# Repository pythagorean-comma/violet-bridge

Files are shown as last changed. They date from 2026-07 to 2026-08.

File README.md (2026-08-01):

# violet-bridge
CadQuery based python scripts to generate STEP and SVG renderings of components of a viola da gamba bridge.
The bridge saddles can be moved fore and aft to allow fine intonation adjustments
The saddles have recesses such that RMC pizz/arco pickups can be installed.

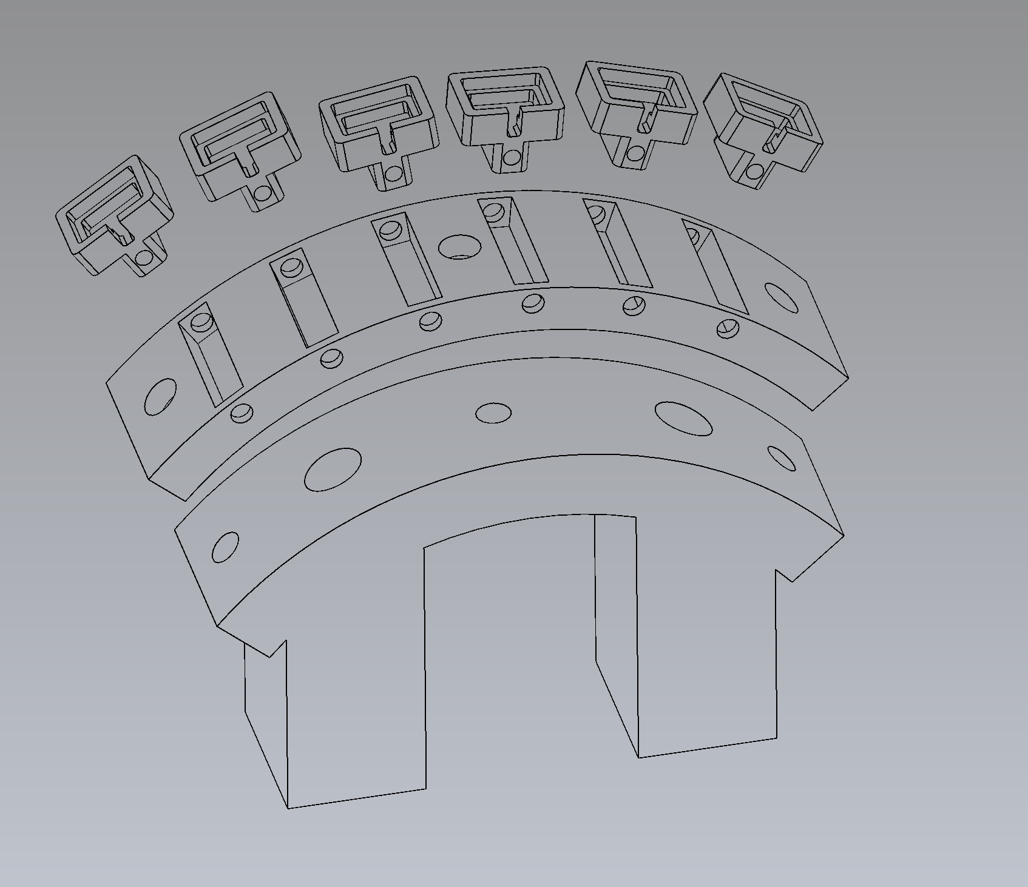
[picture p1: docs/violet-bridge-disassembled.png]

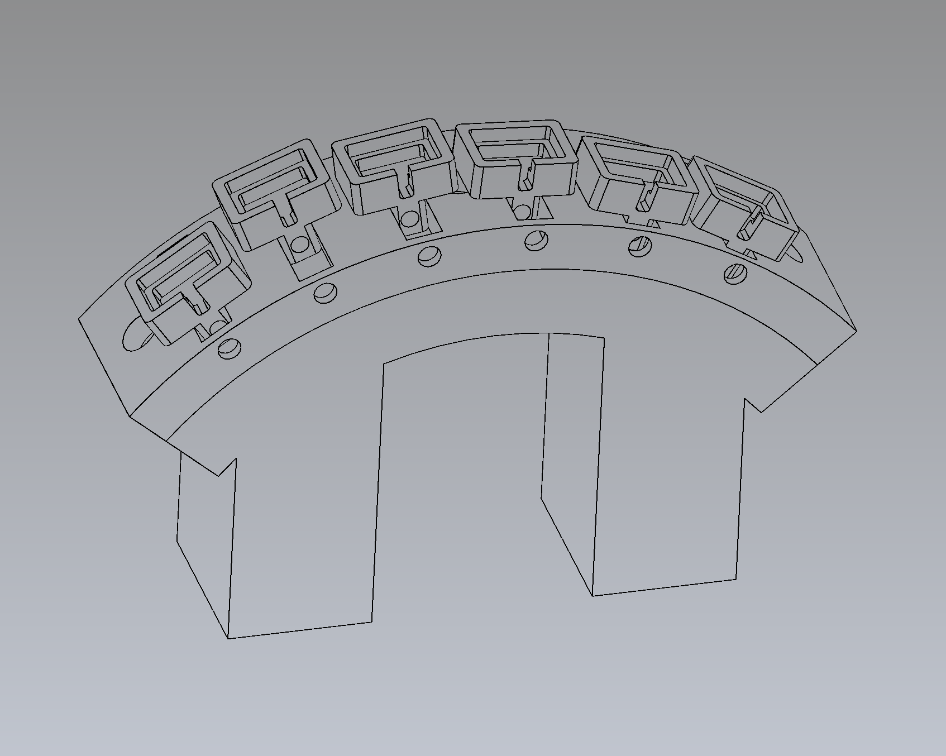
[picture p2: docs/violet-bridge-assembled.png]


## Requirements

`bridge.py`, `bridge_body.py`, `assembly.py`:

```bash
python3 -m venv .venv && .venv/bin/pip install -r requirements.txt
.venv/bin/python assembly.py
```

Python 3.10–3.12. Use `.venv/bin/python` rather than a bare `python`.

## Pickup electronics

The phase-switching preamp for the RMC pizz/arco pickups that sit in the
saddles has its own repository:
<https://github.com/pythagorean-comma/rmc-pizz-arco>. It was extracted from
this one on 2026-08-01 — it shares no dependencies with the bridge geometry
and needs KiCad rather than CadQuery.

The board's history up to that point is in this repository, at the
`electronics/` path. That includes the original 88 × 112 mm hand-buildable
version, which the new repository does not carry:

```bash
git checkout a670b3e -- electronics/
```

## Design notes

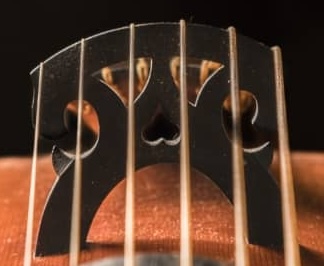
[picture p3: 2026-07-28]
docs/vdg-bridge.jpg

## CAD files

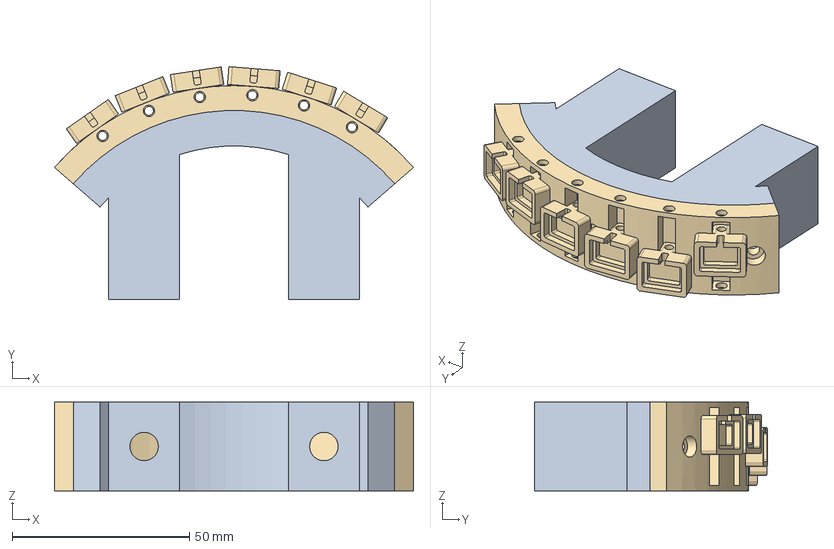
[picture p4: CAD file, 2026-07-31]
out/bridge_assembly.step
101.2 x 65.6 x 25.0 mm
bridge_body
crown
saddle_1
saddle_2
saddle_3
saddle_4
saddle_5
saddle_6

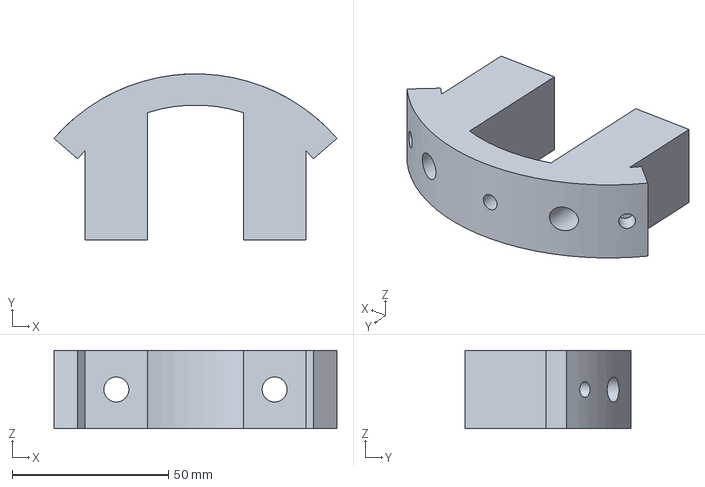
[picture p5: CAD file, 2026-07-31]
out/bridge_body.step
90.6 x 53.2 x 25.0 mm

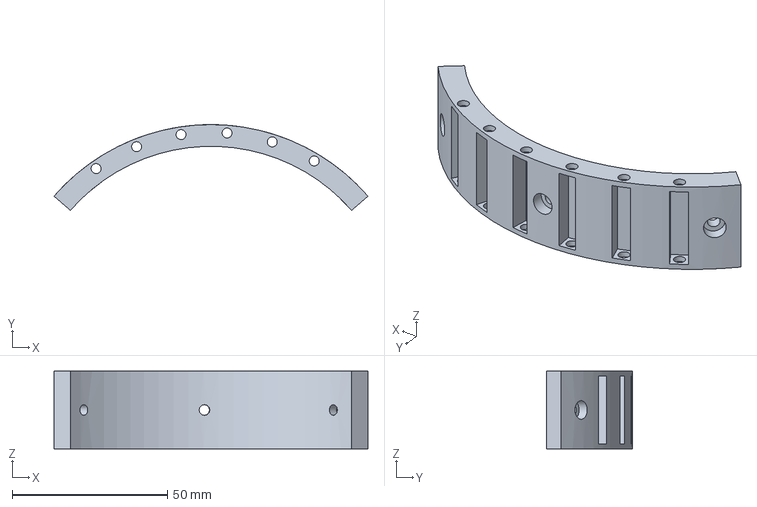
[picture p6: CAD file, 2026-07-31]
out/saddle_bridge.step
101.2 x 27.7 x 25.0 mm

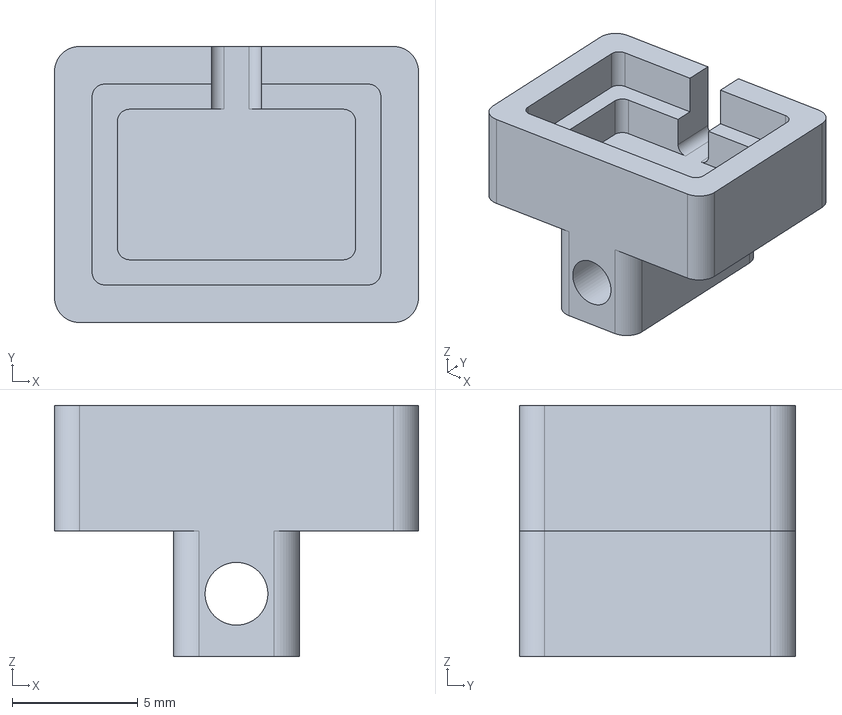
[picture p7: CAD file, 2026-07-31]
out/intonation-carriage.step
14.5 x 11.0 x 10.0 mm

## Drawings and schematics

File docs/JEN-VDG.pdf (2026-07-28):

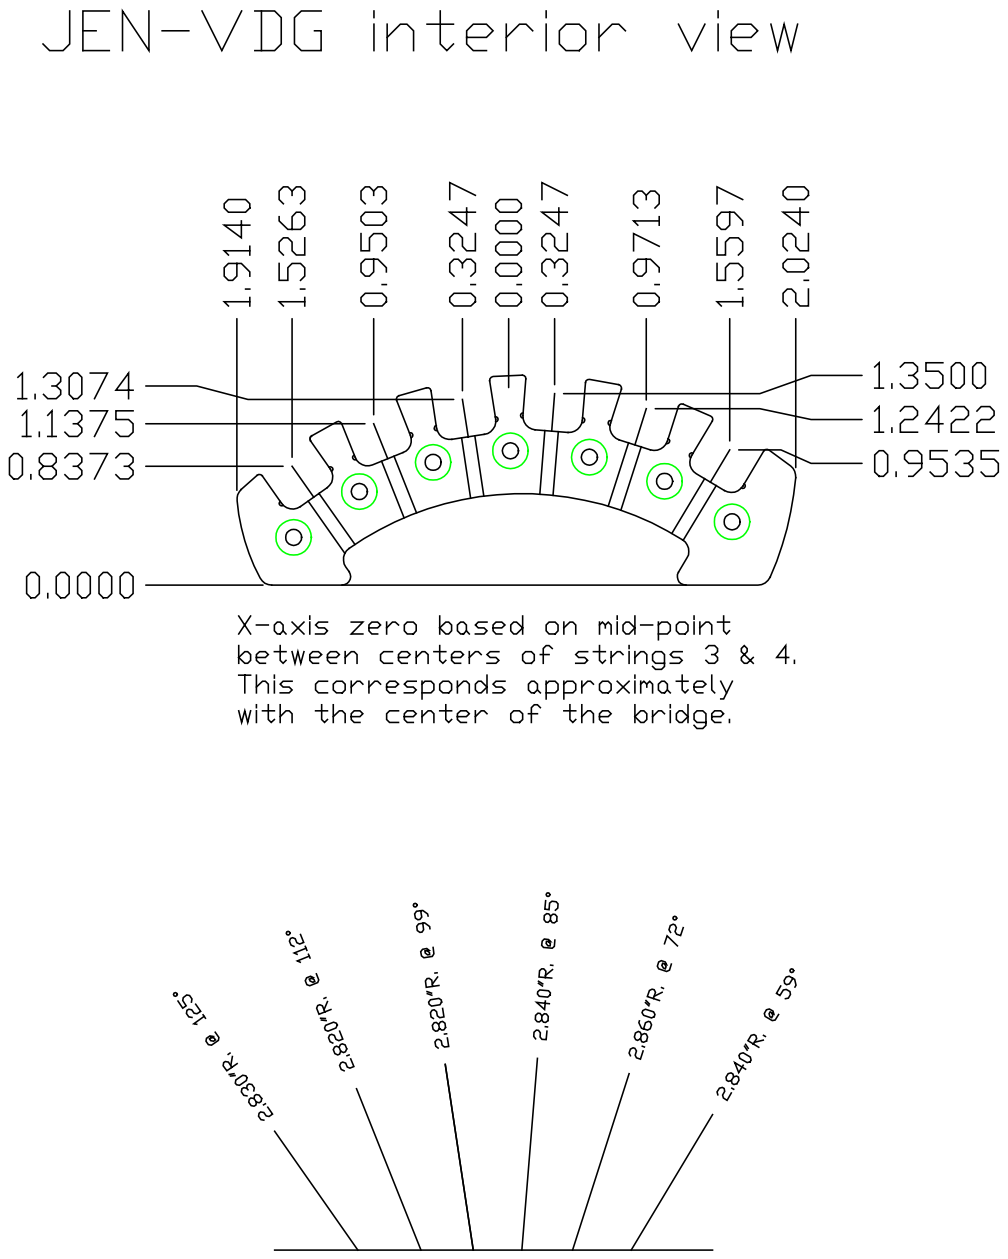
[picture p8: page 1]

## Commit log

2026-07-28 Initial commit of CadQuery script
    [bridge_blank.step]
2026-07-28 Simplified bridge design and made it compatible with abr-1 style saddles with intonation screws. Leaving original Jensen VDG design in case we need to verify radius, string separation, degrees betwee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
    [bridge_blank.step, saddle_bridge.step]
2026-07-28 The original RMC/Jensen design had the strings rotated 2 degrees from centre. This assymetry is useful in that in gives the desired string heights so this has been reinstated
    [saddle_bridge.step]
2026-07-28 Added jpg of a target design
    [saddle_bridge.step]
2026-07-29 This part will dock on to another piece. To facilitate this we have refactored common data points and defs into a common.py. Also added fixing holes to the existing piece such that m3 bolts can be fi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
    [saddle_bridge.step]
2026-07-29 The crown was originally 13.1mm thick radially. We have reduced this to 7mm such that there is now 44% less material.
    [saddle_bridge.step]
2026-07-29 Initial modelling of bridge body
    [bridge_body.step, saddle_bridge.step]
2026-07-29 Moved outer two fixing holes to the outside of outer two strings
    [bridge_body.step, saddle_bridge.step]
2026-07-29 Added legs
    [bridge_body.step]
2026-07-29 Moved legs in 5mm towards centre to accomodate later fitting of a yamahiko contrabass pickup
    [bridge_body.step]
2026-07-29 Added script which assembles both parts for visual verification
    [bridge_assembly.step, bridge_body.step, saddle_bridge.step]
2026-07-29 Initial commit of printed circuit board design for pizz-arco phase shifting
    [rmc-pizz-arco.kicad_pcb, rmc-pizz-arco.kicad_sch]
2026-07-29 Fixed errors and wrote up notes
    [rmc-pizz-arco-B_Courtyard.gbr, rmc-pizz-arco-B_Cu.gbl, rmc-pizz-arco-B_Fab.gbr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]
2026-07-30 Fixed errors and wrote up pcbway order
    [bridge_assembly.step, bridge_body.step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]
2026-07-30 Made the assets accessible as a KiCad project
    [rmc-pizz-arco-B_Cu.gbl, rmc-pizz-arco-B_Mask.gbs, rmc-pizz-arco-B_Silkscreen.gbo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]
2026-07-30 We believe this system can be safely run at 9v DC. We now check for KiCad installation and fail if not found. We updated docs on what happens if the power supply fails.
    [bridge_assembly.step, bridge_body.step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]
2026-07-30 Made it clear that we believe this system can run on 9v
    [rmc-pizz-arco-B_Cu.gbl, rmc-pizz-arco-B_Mask.gbs, rmc-pizz-arco-B_Silkscreen.gbo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]
2026-07-30 Added the current state of the design. Clarifications from RMC will fundamentally change things. Awaiting repsonse before proceeding
2026-07-31 Power is delivered to the pc board via a modified version of the poly-drive ii
2026-07-31 added intonation carriage to this project to keep all assets in one place
    [bridge_blank.step, intonation-carriage.step]
2026-07-31 Updated assembly to include the intonation saddles
    [bridge_assembly.step, bridge_body.step, saddle_bridge.step]
2026-08-01 First pass at reworking board now we know that power will be provided by a modified poly-drive ii via pins 7 and 8
    [rmc-pizz-arco.kicad_pcb, rmc-pizz-arco.kicad_sch]
2026-08-01 DRC is down to 139 from 252 at the start of this session
    [rmc-pizz-arco.kicad_pcb]
2026-08-01 Route the board to DRC-clean: 139 violations to zero
    The routing is now entirely in gen_pcb.py; no autorouter is involved and
    none is needed. 139 -> 34 -> 21 -> 18 -> 1 -> 0, with 0 unconnected items.
    The full build passes: 53 nets and 233 pin connections matched against
    design.py, 80 footprints linked, ERC clean, and the fab package writes.
    Board measures 78.8 x 81.3 mm = 6406 mm2, against 88 x 112 = 9856 on main.
    What the six-at-a-time faults turned out to be, since they are what the
    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
    [rmc-pizz-arco-bom.csv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]
2026-08-01 Stage 5: bring the four documents up to the built board
    STATE.md, NOTES.md, ENCLOSURE.md and fab/ORDER.md all described a board that
    no longer exists. Each now describes the one that does.
    STATE.md was still saying the headroom question was open and no rework had
    started; both were false. It now opens with the built state and carries RMC's
    round-four answer with its date, the reasoning, and — the part that was
    missing — what would falsify it and what the fix would be if it were. The
    ~60 x 70 projection is replaced by the measured 78.8 x 81.3, along with an
    account of why the projection missed by 34%: counting parts rather than
    counting lanes, which is the same error as the two before it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
    [rmc-pizz-arco-B_Cu.gbl, rmc-pizz-arco-B_Mask.gbs, rmc-pizz-arco-B_Silkscreen.gbo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]
2026-08-01 Make the silkscreen legible
    Not a DRC error, and worse for it: the reference designators are what an
    assembler and a reviewer both work from, and half of them were unreadable.
    Three faults, all visible only in a render:
    - Adjacent blocks' sub-row designators landed on top of each other. KiCad
    puts a reference above its part, which for an odd channel points straight
    at the previous block's sub-row 2.8mm away. Sub-row designators now go
    towards their own row instead, mirrored by the channel's sign like
    everything else in a block.
    - Both bottom legends ran off both edges of the board, which a fab silently
    clips -- taking the polarity warning with it, the one piece of silkscreen
    th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
    [rmc-pizz-arco-B_Cu.gbl, rmc-pizz-arco-B_Mask.gbs, rmc-pizz-arco-B_Silkscreen.gbo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]
2026-08-01 Delete fab/board-top.svg -- a render of a board that no longer exists
    It was a top-layer render of the original 88 x 112 mm board (the SVG header
    still said 87.9856 x 111.9886 mm), two revisions behind the 78.8 x 81.3 mm
    board now in fab/. Committed by hand in a14ced1 and never touched since.
    It went stale because it was the one file in fab/ that build.sh did not
    produce, so no build could ever refresh it -- sitting among twelve current
    outputs, where it invited being taken for one of them. That is the whole
    argument for removing it rather than regenerating it: fab/ is trustworthy
    exactly to the extent that everything in it is generated.
    Nothing referenced it. RMC-QUESTIONS.md mentions bui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
2026-08-01 Make free_offset() measure pad edges, not pad centres
    Carried over from a parallel read-only session that spotted it while working
    the same routing problem. It is the one observation from that design still
    worth acting on -- the rest was overtaken by the route that shipped.
    The test compared pad CENTRES against a single 0.55mm scalar. It could not
    tell a 1206's 1.12 x 1.75mm pad from a 2.54mm header's 1.70mm square one, and
    a via needs 0.5mm of room from a pad's EDGE (0.3 radius + 0.2 clearance), so
    clearing a header pad needs 1.35mm between centres. The test asked for 0.55.
    It also counted same-net pads, which need no clearance at all.
    Demonstrated on real geometry: J1.1 and J1.2 are 2.54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
2026-08-01 Move the pickup electronics out to its own repository
    The board is finished and has nothing in common with the bridge geometry it
    was sitting beside: it needs KiCad, not CadQuery, and shares no dependency
    with anything else here. It now lives at
    https://github.com/pythagorean-comma/rmc-pizz-arco.
    History is deliberately not carried across -- it is all still here under
    electronics/, which is where to look for how the board got to where it is.
    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
    [rmc-pizz-arco-bom.csv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]
2026-08-01 Point the README at the electronics history, not at a directory
    The pointer added when the board moved out ended "the history up to that
    point is still here, under electronics/". True of the history and false of
    the working tree: once this lands on main there is no such directory, so
    anyone following the sentence finds nothing.
    Names the path as a historical one instead, and gives the checkout that
    brings it back -- including the original 88 x 112 mm hand-buildable board,
    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
